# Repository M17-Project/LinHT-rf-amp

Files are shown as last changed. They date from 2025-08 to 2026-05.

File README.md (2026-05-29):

[][cc-by-nc-sa]

# LinHT-rf-amp

Standalone RF power amplifier module for the LinHT handheld, built around the **Guerrilla RF GRF5604**.  
This repository houses a proof-of-concept (PoC) board used to evaluate matching, biasing, efficiency, and linearity in the **420–450 MHz** band. Results from this effort will feed back into, and eventually be integrated with the
[main LinHT hardware project](https://github.com/M17-Project/LinHT-hw).

> Goal: validate a practical PA chain for LinHT. Once the approach is proven, the PA will be integrated into LinHT to enable higher output power (targeting ≈ 5 W at the radio level). This board is for laboratory development and characterization.

## Status

- **Design tested - works.**
- Tuning follows the vendor's reference design for **397–470 MHz**

## Safety & Compliance

This hardware is intended for **licensed amateur radio** experimentation. Users are responsible for ensuring compliance with local regulations (spectral masks, occupied bandwidth, power limits, spurious emissions) before on-air use.

## License

This work is licensed under a  
[Creative Commons Attribution-NonCommercial-ShareAlike 4.0 International License][cc-by-nc-sa].

[][cc-by-nc-sa]

[cc-by-nc-sa]: http://creativecommons.org/licenses/by-nc-sa/4.0/
[cc-by-nc-sa-image]: https://licensebuttons.net/l/by-nc-sa/4.0/88x31.png
[cc-by-nc-sa-shield]: https://img.shields.io/badge/License-CC%20BY--NC--SA%204.0-lightgrey.svg

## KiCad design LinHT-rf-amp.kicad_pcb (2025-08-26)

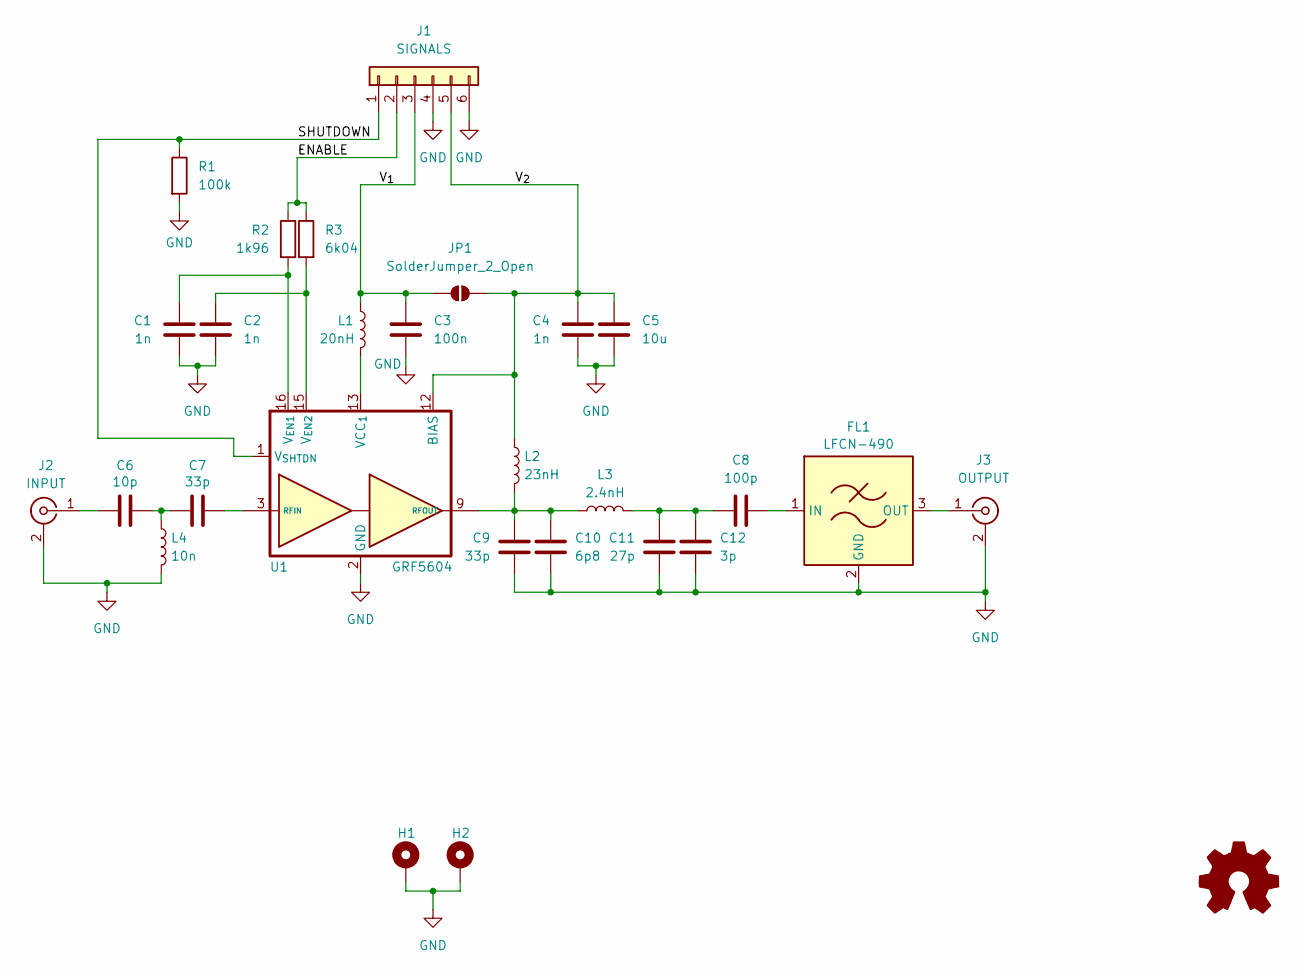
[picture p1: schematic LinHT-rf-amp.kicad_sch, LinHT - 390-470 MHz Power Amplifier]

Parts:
C1, C2, C4: 1n; C_0402_1005Metric; LCSC C161523
C3: 100n; C_0402_1005Metric; LCSC C913614
C5: 10u; C_0402_1005Metric; LCSC C237279
C6: 10p; C_0402_1005Metric; LCSC C782046
C7, C9: 33p; C_0402_1005Metric; LCSC C464434
C8: 100p; C_0402_1005Metric; LCSC C77177
C10: 6p8; C_0402_1005Metric; LCSC C88896
C11: 27p; C_0402_1005Metric; LCSC C88883
C12: 3p; C_0402_1005Metric; LCSC C88891
FL1: LFCN-490; Filter_Mini-Circuits_FV1206; LCSC C3008205
H1, H2: MountingHole_Pad_MP; MountingHole_2.2mm_M2_DIN965_Pad
J1: SIGNALS; PinHeader_1x06_P2.54mm_Vertical
J2: INPUT; SMA_Amphenol_132289_EdgeMount
J3: OUTPUT; SMA_Amphenol_132289_EdgeMount
JP1: SolderJumper_2_Open; SolderJumper-2_P1.3mm_Open_RoundedPad1.0x1.5mm
L1: 20nH; L_0402_1005Metric; LCSC C20623501
L2: 23nH; 0908SQ-23N; LCSC C42418190
L3: 2.4nH; L_0603_1608Metric; LCSC C2042508
L4: 10n; L_0402_1005Metric; LCSC C668375
R1: 100k; R_0402_1005Metric; LCSC C25741
R2: 1k96; R_0402_1005Metric; LCSC C70427
R3: 6k04; R_0402_1005Metric; LCSC C25913
SYM1: Logo_Open_Hardware_Small; OSHW-Logo2_7.3x6mm_SilkScreen
U1: GRF5604; QFN-16-1EP_3x3mm_P0.5mm_EP1.7x1.7mm_ThermalVias

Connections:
/ENABLE: J1.2, R2.1, R3.1
/SHUTDOWN: J1.1, R1.1, U1.1 (V_{SHTDN})
/V_{1}: C3.2, J1.3, JP1.1 (A), L1.1
/V_{2}: C4.2, C5.2, J1.5, JP1.2 (B), L2.1, U1.12 (BIAS)
GND: C1.2, C2.2, C3.1, C4.1, C5.1, C9.1, C10.1, C11.1, C12.1, FL1.2 (GND), FL1.4 (GND), H1.1, H2.1, J1.4, J1.6, J2.2 (Ext), J3.2 (Ext), L4.2, R1.2, U1.2 (GND), U1.5 (GND), U1.6 (GND), U1.7 (GND), U1.8 (GND), U1.11 (GND), U1.14 (GND), U1.17 (GND)
unnamed: C6.2, C7.1, L4.1
unnamed: C7.2, U1.3 (RFIN), U1.4 (RFIN)
unnamed: C9.2, C10.2, L2.2, L3.1, U1.9 (RFOUT), U1.10 (RFOUT)
unnamed: C8.1, C11.2, C12.2, L3.2
unnamed: C8.2, FL1.1 (IN)
unnamed: FL1.3 (OUT), J3.1 (In)
unnamed: C6.1, J2.1 (In)
unnamed: L1.2, U1.13 (VCC_{1})
unnamed: C1.1, R2.2, U1.16 (V_{EN1})
unnamed: C2.1, R3.2, U1.15 (V_{EN2})

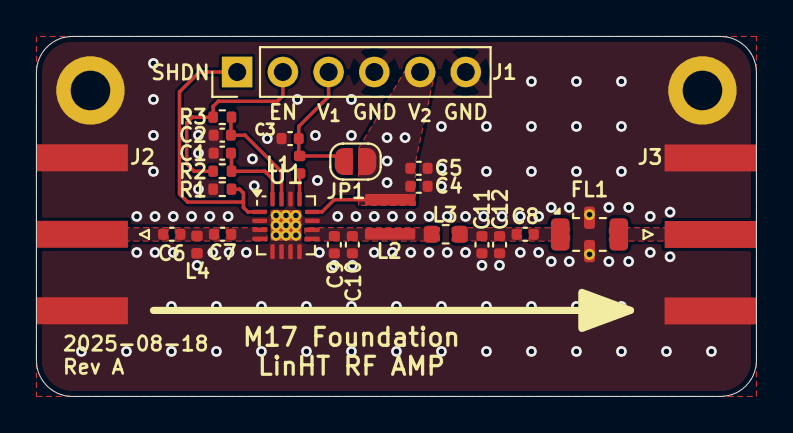
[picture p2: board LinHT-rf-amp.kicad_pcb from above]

Board: 4 copper layers, 40.0 x 20.0 mm, 27 parts (0 on the bottom side), 15 nets.

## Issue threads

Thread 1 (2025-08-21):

Needs more thermal vias under the amp

featherfeet, 2025-08-21:
I strongly suspect 4 vias will not be sufficient to sink heat into the board when transmitting for a while (exact numbers depend on the stackup you choose). The eval board has more vias under the chip for thermal reasons. See https://www.ti.com/lit/an/snva419c/snva419c.pdf?ts=1755739156838 for how to calculate thermal impedance of PCB vias.

Closed 2025-08-25.

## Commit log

2025-08-17 Added a basic schematics (using KiCAD 9.0)
    [LinHT-rf-amp.kicad_pcb, LinHT-rf-amp.kicad_sch]
2025-08-18 Added component values and connectors
    [LinHT-rf-amp.kicad_sch]
2025-08-19 Modified the GRF5604 symbol
    [LinHT-rf-amp.kicad_sch]
2025-08-19 Added footprint and 3D model for the 23nH Coilcraft coil
2025-08-19 Added LCSC and manufacturer numbers for all components
    [LinHT-rf-amp.kicad_sch]
2025-08-19 Added signal names to the schematics
    [LinHT-rf-amp.kicad_sch]
2025-08-19 Finished basic layout
    * 4 layer board
    * Dimensions 35x20 mm
    [LinHT-rf-amp.kicad_pcb]
2025-08-19 Fixed RF traces, reset annotation, added M2 holes
    [LinHT-rf-amp.kicad_pcb, LinHT-rf-amp.kicad_sch]
2025-08-19 Added more vias and via fencing around RF traces
    [LinHT-rf-amp.kicad_pcb]
2025-08-20 Modified "copper to edge" clearance from 0.5 to 0.3 mm
    Tjis value is b ased on the PCBway recommendation.
    [LinHT-rf-amp.kicad_pcb]
2025-08-20 Excluded J1-J3 from position files
    [LinHT-rf-amp.kicad_pcb]
2025-08-20 Added a low pass filter LFCN-490+
    [LinHT-rf-amp.kicad_sch]
2025-08-20 Updated layout with the low pass filter
    Board dimensions has to be increased to 40x20 mm (original 35x20mm)
    [LinHT-rf-amp.kicad_pcb]
2025-08-25 Changed footprint of the GRF5604 to the QFN-16 with 9 vias
    Default KiCAD footprint for QFN-16-1EP_3x3mm_P0.5mm_EP1.7x1.7_ThermalVias
    has only four 0.2 mm vias in the GND pad corners. This is not enough
    to transfer the heat.
    This commit modifies the default footprint to have 9 vias of 0.3 mm.
2025-08-25 Updated design to use new GRF5604 footprint
    [LinHT-rf-amp.kicad_pcb, LinHT-rf-amp.kicad_sch]
2025-08-25 Fixed shape of the V2 signal polygon on the top layer
    [LinHT-rf-amp.kicad_pcb]
2025-08-25 Remove alternative part number for the L2 coil
    Original Coilcraft coil 0908SQ-23NJLC is not easily available at LCSC,
    so we chose the alternative part XR0908SQ-23NJLC with the same params.
    [LinHT-rf-amp.kicad_pcb, LinHT-rf-amp.kicad_sch]
2025-08-26 Fixed position of the bottom silkscreen text
    [LinHT-rf-amp.kicad_pcb]
2025-08-26 silkscreen update
    frequency range starts at 397 MHz
    [LinHT-rf-amp.kicad_pcb]
2025-08-26 title update
    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
    [LinHT-rf-amp.kicad_sch]

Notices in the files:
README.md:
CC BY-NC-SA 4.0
